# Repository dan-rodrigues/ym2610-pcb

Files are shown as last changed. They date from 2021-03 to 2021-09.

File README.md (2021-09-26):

# YM2610 PCB

This project allows the user to control a YM2610(B) FM synthesis / ADPCM / SSG sound chip. Software is included to play back YM2610(B) VGM files which includes any Neo Geo arcade game and various others. It can also play certain Sega Genesis tracks using an included converter script. There is also a MIDI input that can be paired with new software to control the synth.

The goal is to make the complete system both low-cost and flexible which increases the complexity of the FPGA design but allows the use of cheaper hardware (i.e. a $35USD FPGA board and a fairly straightforward PCB).

The FPGA board used is the [iCEBreaker Bitsy](https://1bitsquared.com/collections/fpga/products/icebreaker-bitsy) which is also [open source](https://github.com/icebreaker-fpga/icebreaker). It's the small purple board in the bottom left of the photo. A custom vendor USB device and a companion host Python script is used for control. The USB core used is [no2usb](https://github.com/no2fpga/no2usb).

## Assembled PCBs

### v1.1.0 (partial)

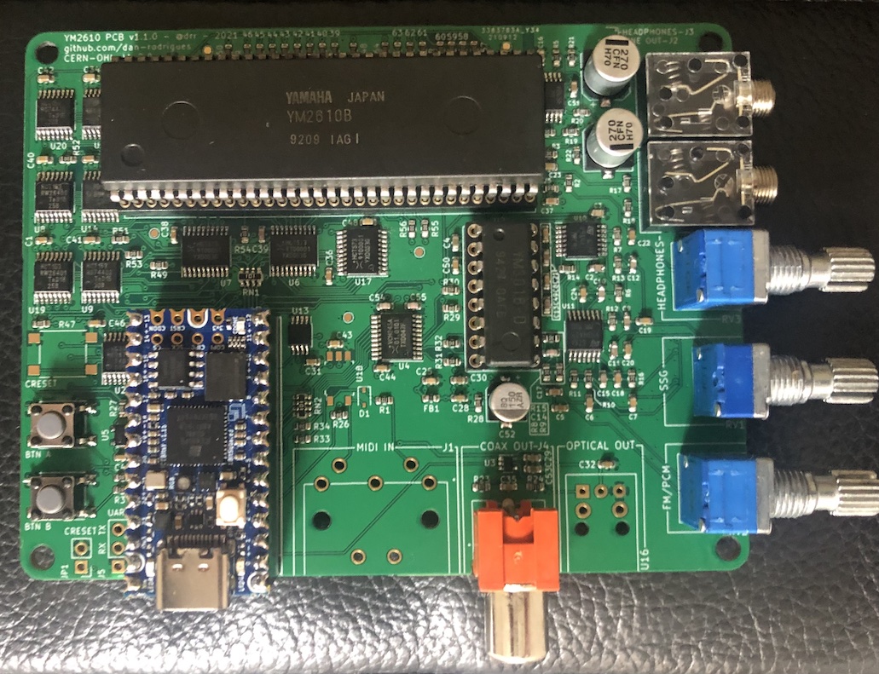
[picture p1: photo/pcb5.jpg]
v1.1.0 PCB partially assembled


### v1.0.1

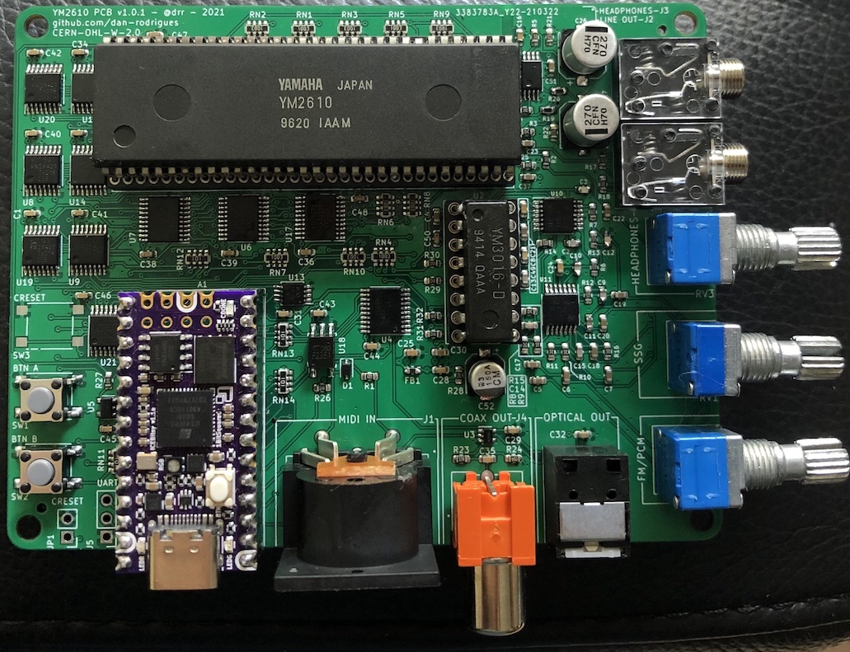
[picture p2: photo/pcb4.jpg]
v1.0.1 PCB assembled


## Video/Audio demos

* [Metal Slug 2 soundtrack](https://www.youtube.com/watch?v=nlexW8DgMvw) - Neo Geo VGM playback demo using S/PDIF audio output.
* [Thunder Force IV soundtrack](https://www.youtube.com/watch?v=O-OgxfgEnMU) - Sega Genesis playback demo using analog line-out output.

The Sega Genesis demos are made using an included converter script to compensate for incompatible hardware, different clock rates and differences in PCM playback.

## Features

### I/O

* S/PDIF compatible outputs. The digital sound sources from the OPNB (FM/PCM) can be heard using this output. The analog sound source (SSG) can only be heard with the 3.5mm analog outputs. Optical and coax outputs are included.
* 3.5mm line out.
* 3.5mm headphone out with attenutation pot.
* Separate attenuation pots for the combined FM/PCM and separate SSG sound sources. Their levels can be adjusted or muted independently.
* MIDI input (DIN-5). Default firmware includes library functions to read the MIDI messages into a minimal struct. There's also a simple FM demo.
* 2x user buttons. The default firmware uses them to cycle through the available sound sources.

The S/PDIF output is resampled to 48KHz and can be used to hear the original lossless output from the OPNB. It doesn't include the analog SSG output but most tracks don't use it.

The analog outputs include an active low pass filter (fC = approx 17KHz), independent attenutation pots for each sound source and can also be used to hear the analog SSG output.

### Debug

These aren't required but can be useful for debugging.

* UART header
* CRESET jumper
* CRESET button

## Operation

Included is also an SoC implementation for the FPGA (in the `rtl/` directory) and firmware that runs on this SoC (in the `fw/` directory). There's also a set of helper scripts to control the SoC over the USB port.

ADPCM samples are fetched from the FPGA board PSRAM. The host PCB itself doesn't include any extra memory, only some standard logic to mux the PCM buses to the limited number of FPGA IO available. The RAM is 64MBit which is smaller than the 128MBit address space of samples, but the player script relocates and remaps samples starting from address 0 if needed. This means tracks that use the 128MBit space will work assuming the total PCM size of the track is less than 64MBit, which it likely is.

Both the original YM3016 DAC and the FPGA have access to the digital outputs of the synth. This means both analog output (using the DAC) and digital output (using the coax/optical output) is available. S/PDIF encoding is done on the FPGA and made available from the digital outputs.

The synth has a pair of PCM buses that work in parallel and the board only includes a single RAM which must be shared. The slower of the two buses is automatically paused when the faster bus begins a read which handles the contention issue. Only 4 FPGA IOs are used to read the 26 PCM bus pins which is handled using standard logic on the board.

The iCEBreaker Bitsy USB port is used to upload music data and also for control. The USB stack used and firmware can be customised as needed i.e. to allow a PC MIDI interface to drive the OPNB, or to record the raw digital output to store on a file, or any other possible use.

There is only 128KByte of RAM available to the software which would limit the maximum size of track that can be played. The track commands are streamed over USB to get around this limit which means tracks can be arbitrarily large. A pair of 8KByte buffers are read/written to support playback of large tracks.

Synth commands are output using a pair of 8bit shift registers, running at the same 8MHz clock as the synth itself. This reduces the needed IO count without being a bottleneck.

## Usage

### Build and flash

This project uses submodules which must be cloned first.

```
git submodule update --init --recursive
```

Building and flashing FPGA bitstream (which implements the SoC):

```
make dfuprog
```

Building and flashing SoC firmware:

```
make -C fw dfuprog
```

### Playing VGM files

After flashing the firmware, the RGB LED should slowly flash indicating that it's ready to use. Either `vgz` or `vgm` files can be used.

```
./scripts/usb_ctrl.py track.vgm
```

More details about the scripts can be found in their [README](scripts/README.md) file.

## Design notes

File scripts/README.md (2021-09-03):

# Scripts

The [usb_ctrl.py](usb_ctrl.py) script is used to play VGM files over USB. Tracks played using usb_ctrl.py are automatically converted if needed before playback. YM2610(B) and YM2612 + PSG tracks are supported with the latter being converted before playback.

## Prerequisites

The [pyusb](https://github.com/pyusb/pyusb) library is required.

```
pip3 install -r requirements.txt
```

## Usage

These scripts can be used in one of two ways.

### USB driver

To upload a supported VGM file and start playback:

```
./usb_ctrl.py <vgm_file_to_play>
```

### VGM converter

A wrapper script can be used to do limited conversion of a YM2612 + SN76489 VGM to a YM2610B VGM. The output could also be played on a YM2608 since they have common FM / SSG sound sources. Note that the regular YM2610 (non-B variant) can play the result but only with 4 out of 6 FM channels.

* All OPN FM pitches are converted according to the input clock to an assumed 8MHz output clock so clock differences should not change the effective pitch.
* PSG square waves are replaced with equivalent SSG square waves with pitch adjustment, which then played using the integrated YM2149.
* The YM2612 DAC channel output is encoded as a set of ADPCM-B samples for playback on the YM2610.

Because the SN76489 and YM2149 don't have identical features, the conversion is only partial. There is currently no attempt to convert noise playback.

```
./vgm_convert.py <input_vgm> <output_vgm>
```

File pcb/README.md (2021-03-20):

# PCB

Included is the schematic and PCB layout of the board.

## Usage

Most ICs on the board are optional but a few are required in any case:

* 2x 74AHCT595: Shift registers to control the YM2610(B) and reset both the 2610 and the 3016.
* 1x 74LV1T34: Clock buffer, also shifts the 8MHz clock from 3.3v to 5v.

If ADPCM-A/B playback is needed, then these are required:

* 4x 74HCT153
* 1x 74LVC257
* 1x 74LVC2G08
* 1x 74LVC244

The analog section is optional assuming the SSG sound source isn't needed. To listen to the digital sound sources using S/PDIF output, there are optional optical and coax outputs. The coax output does not use a pulse transformer and one can be added if needed. 

## License

CERL-OHL-S-2.0. There is a copy of the text included in the licenses/ directory in the root of this repo. License text can also be found [here](https://ohwr.org/cern_ohl_s_v2.txt).

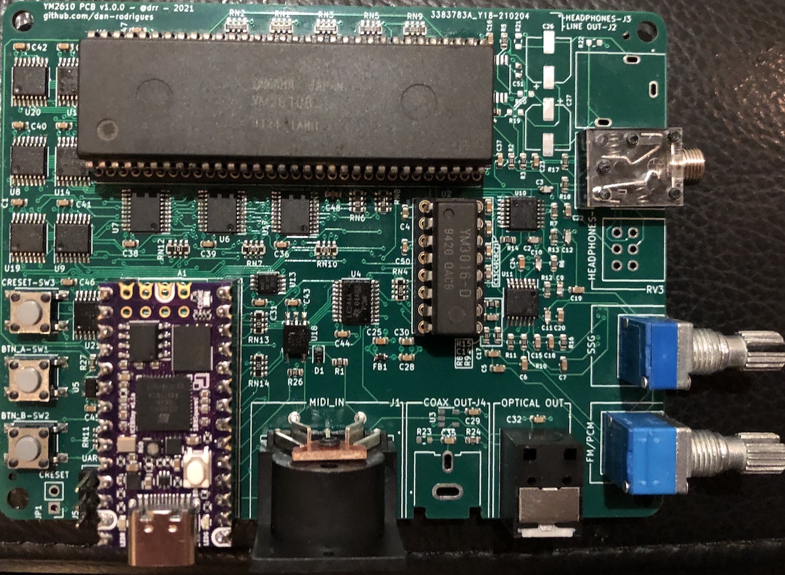
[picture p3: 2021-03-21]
photo/pcb2.jpg

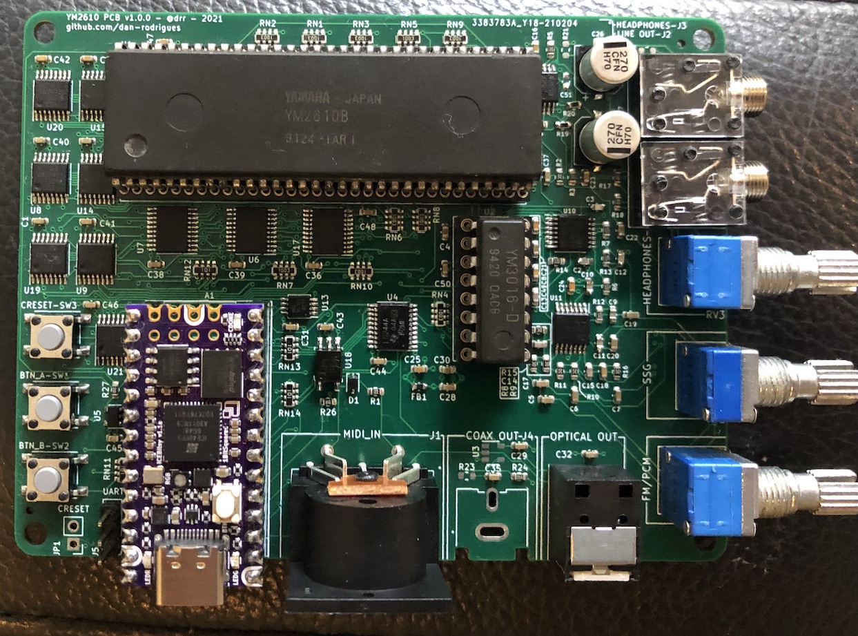
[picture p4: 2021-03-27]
photo/pcb3.jpg

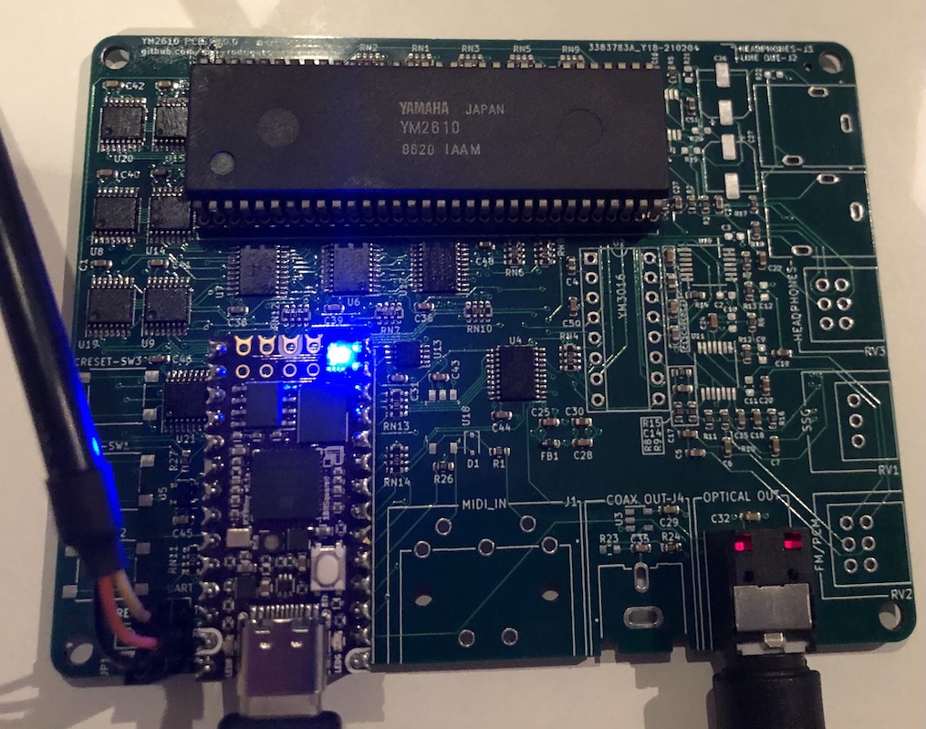
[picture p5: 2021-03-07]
photo/pcb1.jpg

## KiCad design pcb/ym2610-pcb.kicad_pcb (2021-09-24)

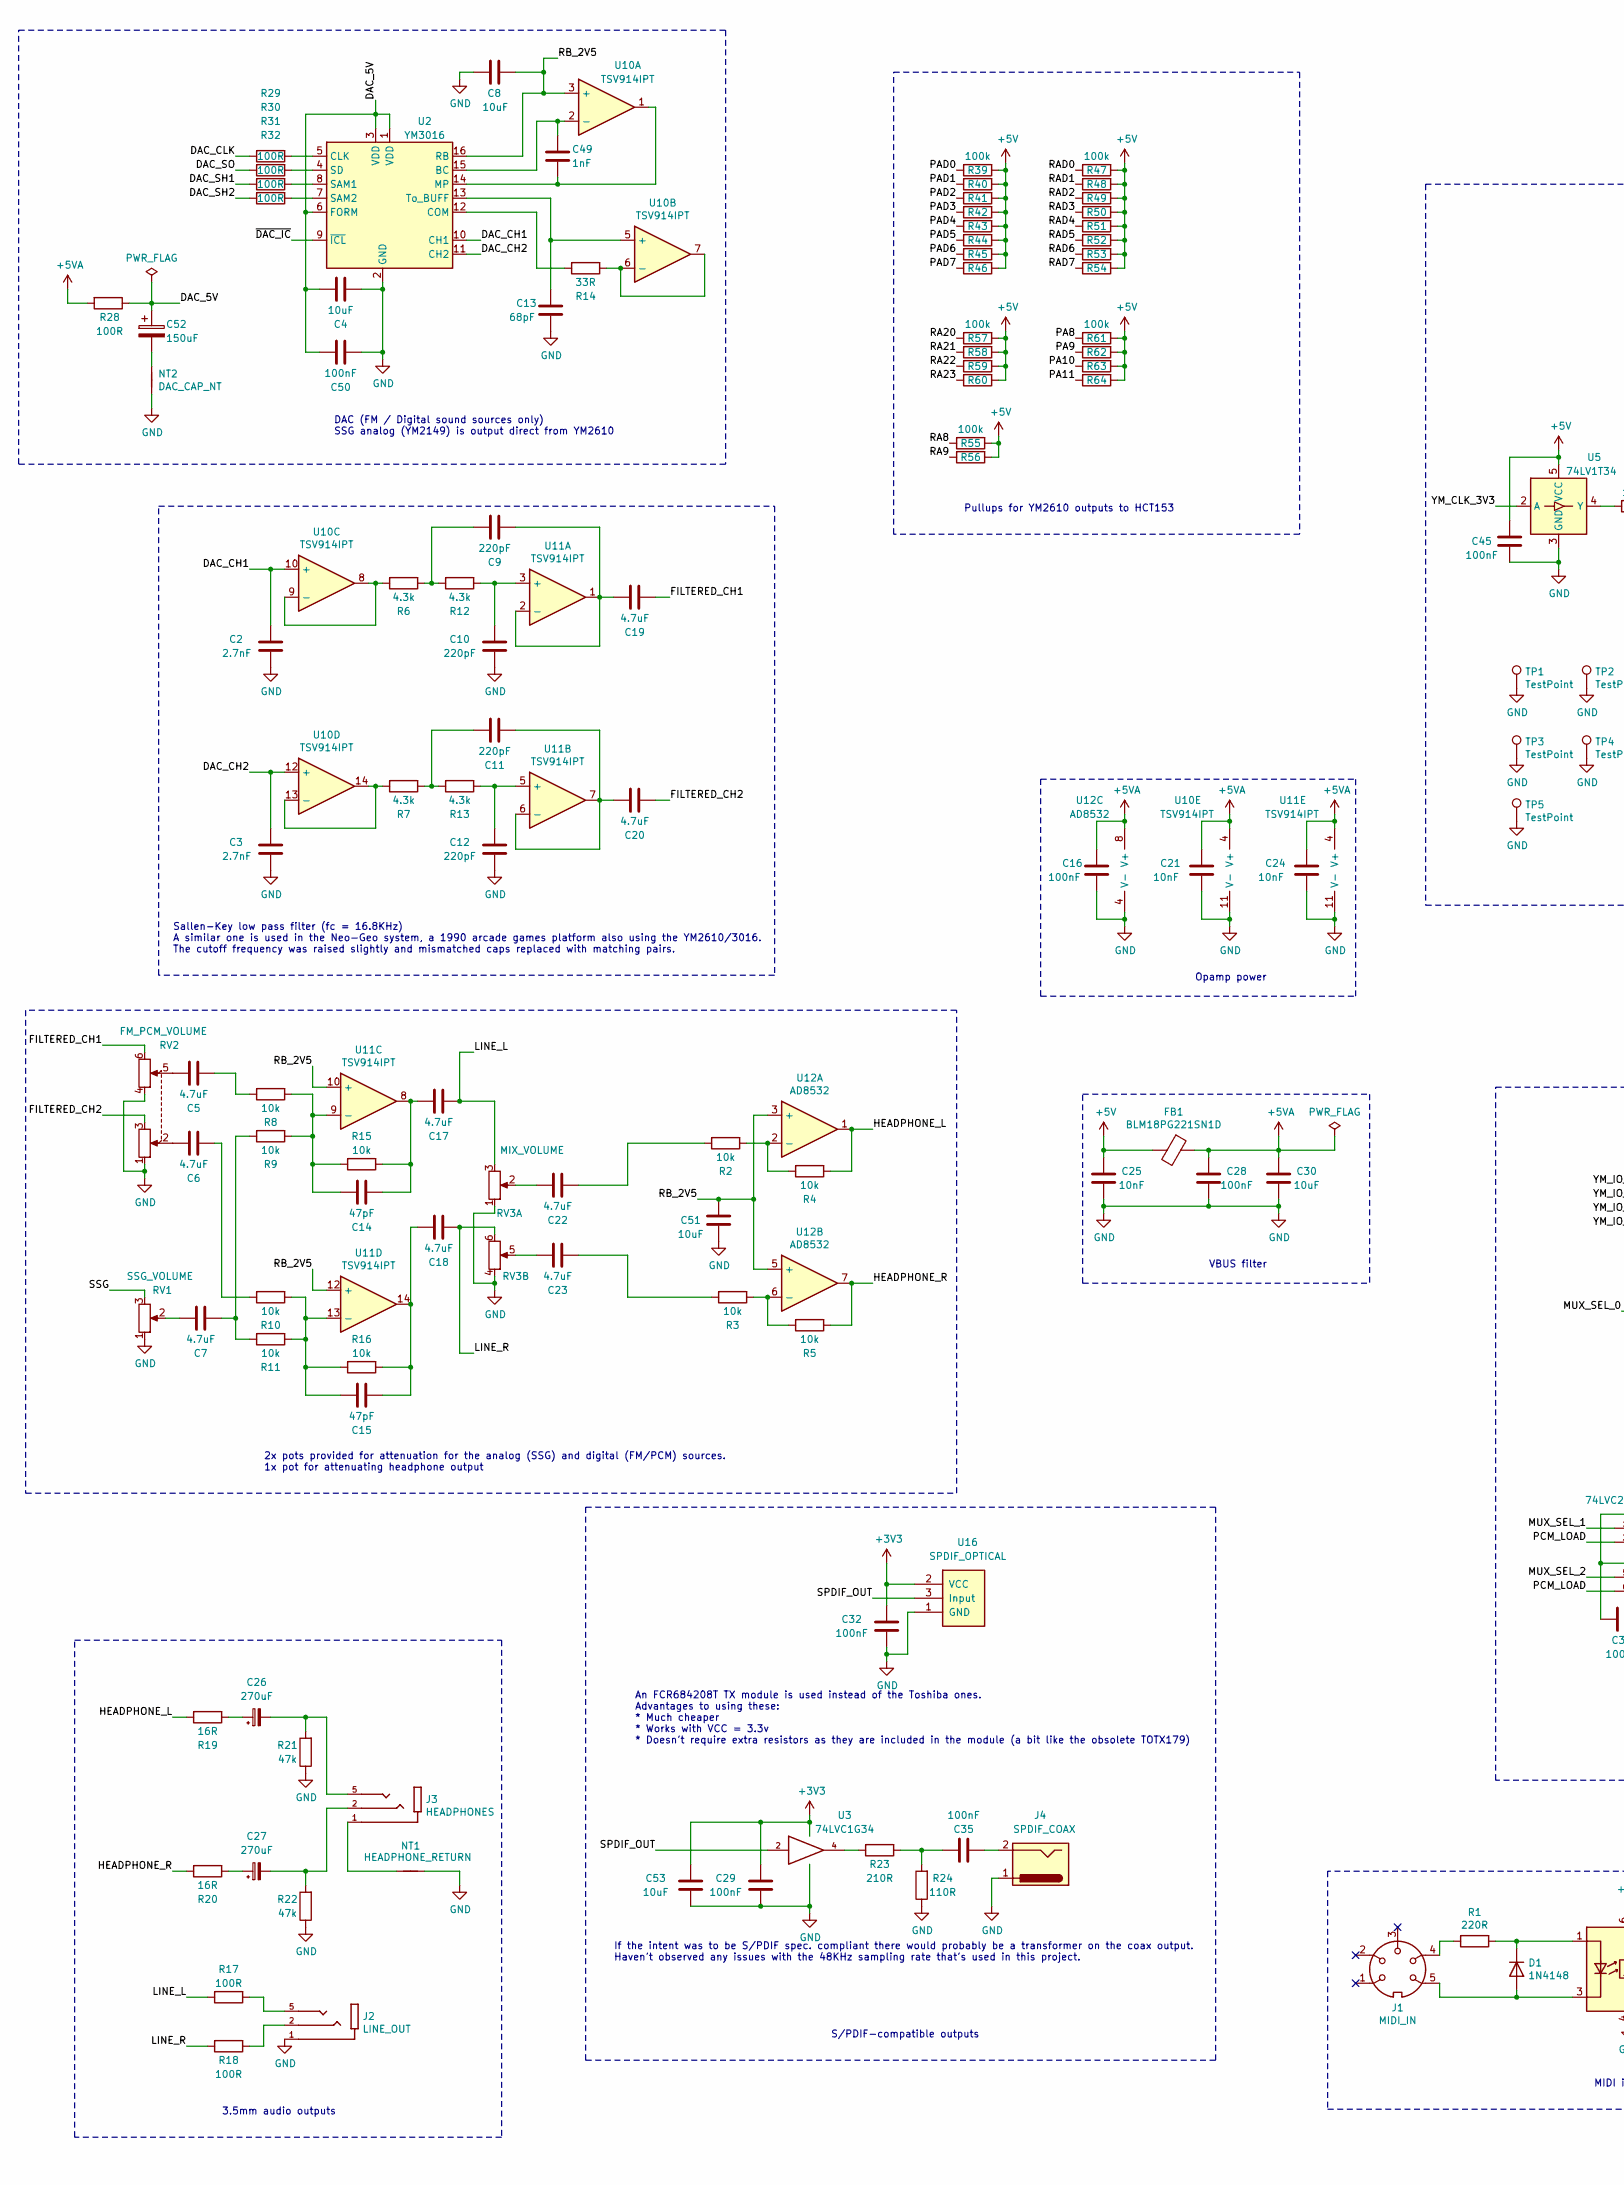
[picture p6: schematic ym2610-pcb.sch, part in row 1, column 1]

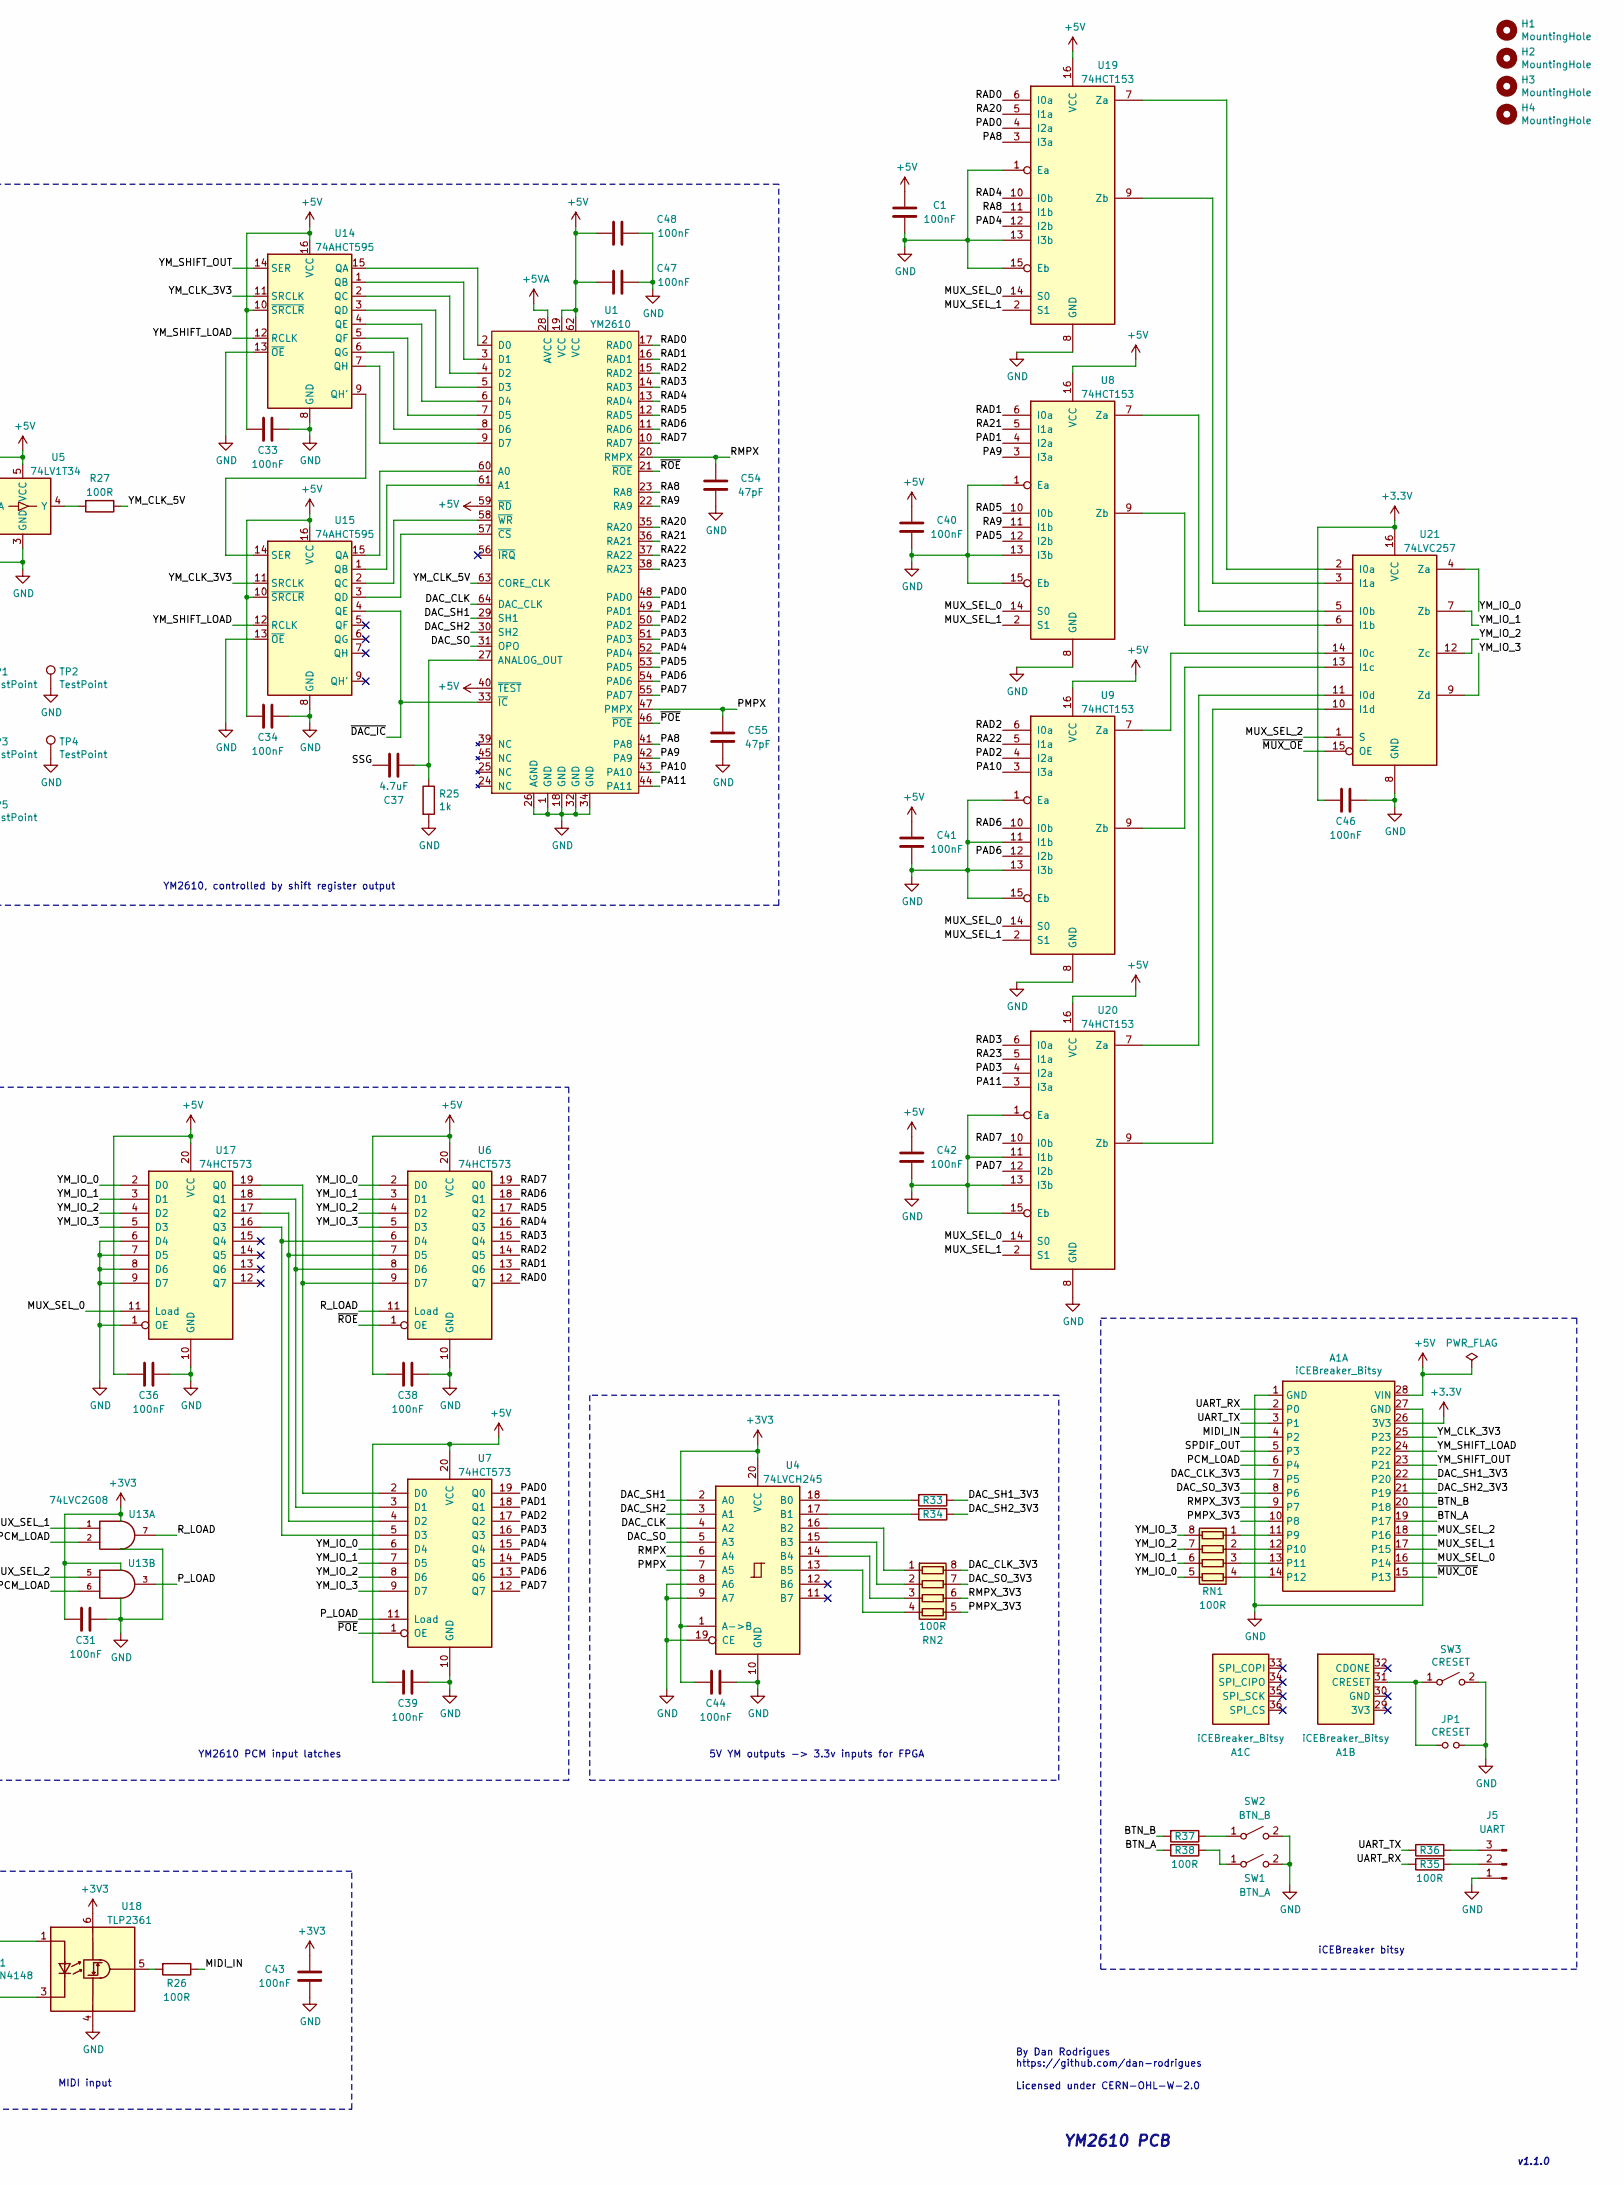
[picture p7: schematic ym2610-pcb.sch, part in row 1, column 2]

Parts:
A1: iCEBreaker_Bitsy; iCEBreaker_Bitsy_THT
C1, C29, C31, C32, C33, C34, C35, C36, C38, C39, C40, C41, C42, C44, C45, C46, C47, C48: 100nF; C_0603_1608Metric
C2, C3: 2.7nF; C_0603_1608Metric; Voltage 10v
C4, C8, C30, C51: 10uF; C_0603_1608Metric; Voltage 10v
C5, C6, C7, C17, C18, C19, C20, C22, C23, C37: 4.7uF; C_0603_1608Metric; Voltage 10v
C9, C10, C11, C12: 220pF; C_0603_1608Metric; Voltage 10v
C13: 68pF; C_0603_1608Metric; Voltage 10v
C14, C15: 47pF; C_0603_1608Metric; Voltage 10v; Tolerance 5%
C16, C28, C50: 100nF; C_0603_1608Metric; Voltage 10v
C21, C24, C25: 10nF; C_0603_1608Metric; Voltage 10v
C26, C27: 270uF; CP_Elec_6.3x7.7; Voltage 10v
C43: 100nF; C_0603_1608Metric; Voltage 3.3v
C49: 1nF; C_0603_1608Metric; Voltage 10v
C52: 150uF; CP_Elec_5x5.8; Voltage 10v
C53: 10uF; C_0603_1608Metric
C54, C55: 47pF; C_0603_1608Metric
D1: 1N4148; D_SOD-323
FB1: BLM18PG221SN1D; L_0603_1608Metric
H1, H2, H3, H4: MountingHole; MountingHole_3.2mm_M3_DIN965
J1: MIDI_IN; CUI_SDS-50J
J2: LINE_OUT; SWITCHCRAFT_35RAPC2BH3; PARTREV J
J3: HEADPHONES; SWITCHCRAFT_35RAPC2BH3; PARTREV J
J4: SPDIF_COAX; RCJ-04
J5: UART; PinHeader_1x03_P2.54mm_Vertical
JP1: CRESET; PinHeader_1x02_P2.54mm_Vertical
NT1: HEADPHONE_RETURN; NetTie-2_SMD_Pad0.5mm
NT2: DAC_CAP_NT; NetTie-2_SMD_Pad0.5mm
R1: 220R; R_0603_1608Metric
R2, R3, R4, R5: 10k; R_0603_1608Metric
R6, R7, R12, R13: 4.3k; R_0603_1608Metric; Tolerance 1%
R8, R9, R10, R11, R15, R16: 10k; R_0603_1608Metric; Tolerance 1%
R14: 33R; R_0603_1608Metric; Tolerance 1%
R17, R18, R26, R27, R28, R29, R30, R31, R32, R33, R34, R35, R36, R37, R38: 100R; R_0603_1608Metric
R19, R20: 16R; R_0603_1608Metric
R21, R22: 47k; R_0603_1608Metric
R23: 210R; R_0603_1608Metric
R24: 110R; R_0603_1608Metric
R25: 1k; R_0603_1608Metric; Tolerance 1%
R39, R40, R41, R42, R43, R44, R45, R46, R47, R48, R49, R50, R51, R52, R53, R54, R55, R56, R57, R58, R59, R60, R61, R62, R63, R64: 100k; R_0603_1608Metric
RN1, RN2: 100R; R_Array_Convex_4x0603
RV1: SSG_VOLUME; PTD901-2015K-A103
RV2: FM_PCM_VOLUME; PTD902-2020K-A103
RV3: MIX_VOLUME; PTD902-2020K-A103
SW1: BTN_A; SW_SPST_PTS645
SW2: BTN_B; SW_SPST_PTS645
SW3: CRESET; SW_SPST_PTS645
TP1, TP2, TP3, TP4, TP5: TestPoint; TestPoint_Pad_D1.0mm
U1: YM2610; DIP-64_W19.05mm_P1.78mm_Socket
U2: YM3016; DIP-16_W7.62mm_Socket
U3: 74LVC1G34; SOT-353_SC-70-5
U4: 74LVCH245; TSSOP-20_4.4x6.5mm_P0.65mm
U5: 74LV1T34; SOT-23-5
U6, U7, U17: 74HCT573; TSSOP-20_4.4x6.5mm_P0.65mm
U8, U9, U19, U20: 74HCT153; TSSOP-16_4.4x5mm_P0.65mm
U10, U11: TSV914IPT; TSSOP-14_4.4x5mm_P0.65mm
U12: AD8532; TSSOP-8_4.4x3mm_P0.65mm
U13: 74LVC2G08; TSSOP-8_3x3mm_P0.65mm
U14, U15: 74AHCT595; TSSOP-16_4.4x5mm_P0.65mm
U16: SPDIF_OPTICAL; FCR684208T
U18: TLP2361; SOIC-6-5_W4.55mm
U21: 74LVC257; TSSOP-16_4.4x5mm_P0.65mm

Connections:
+5V: A1.28 (VIN), C1.2, C25.1, C33.2, C34.2, C36.1, C38.2, C39.2, C40.2, C41.2, C42.2, C45.2, C47.2, C48.2, FB1.2, R39.1, R40.1, R41.1, R42.1, R43.1, R44.1, R45.1, R46.1, R47.1, R48.1, R49.1, R50.1, R51.1, R52.1, R53.1, R54.1, R55.1, R56.1, R57.1, R58.1, R59.1, R60.1, R61.1, R62.1, R63.1, R64.1, U1.19 (VCC), U1.40 (~TEST), U1.59 (~RD), U1.62 (VCC), U5.5 (VCC), U6.20 (VCC), U7.20 (VCC), U8.16 (VCC), U9.16 (VCC), U14.10 (~SRCLR), U14.16 (VCC), U15.10 (~SRCLR), U15.16 (VCC), U17.20 (VCC), U19.16 (VCC), U20.16 (VCC)
+5VA: C16.1, C21.1, C24.1, C28.1, C30.1, FB1.1, R28.2, U1.28 (AVCC), U10.4 (V+), U11.4 (V+), U12.8 (V+)
/BTN_A: A1.19 (P17), R38.2
/BTN_B: A1.20 (P18), R37.2
/DAC_5V: C4.2, C50.2, C52.1, R28.1, U2.1 (VDD), U2.3 (VDD), U2.6 (FORM)
/DAC_CH1: C2.1, U2.10 (CH1), U10.10 (+)
/DAC_CH2: C3.1, U2.11 (CH2), U10.12 (+)
/DAC_CLK: R29.2, U1.64 (DAC_CLK), U4.4 (A2)
/DAC_CLK_3V3: A1.7 (P5), RN2.8 (R1.2)
/DAC_SH1: R31.2, U1.29 (SH1), U4.2 (A0)
/DAC_SH1_3V3: A1.22 (P20), R33.1
/DAC_SH2: R32.2, U1.30 (SH2), U4.3 (A1)
/DAC_SH2_3V3: A1.21 (P19), R34.1
/DAC_SO: R30.2, U1.31 (OPO), U4.5 (A3)
/DAC_SO_3V3: A1.8 (P6), RN2.7 (R2.2)
/FILTERED_CH1: C19.1, RV2.6
/FILTERED_CH2: C20.1, RV2.3
/HEADPHONE_L: R4.1, R19.2, U12.1
/HEADPHONE_R: R5.1, R20.2, U12.7
/LINE_L: C17.1, R17.2, RV3.3
/LINE_R: C18.1, R18.2, RV3.6
/MIDI_IN: A1.4 (P2), R26.1
/MUX_SEL_0: A1.16 (P14), U8.14 (S0), U9.14 (S0), U17.11 (Load), U19.14 (S0), U20.14 (S0)
/MUX_SEL_1: A1.17 (P15), U8.2 (S1), U9.2 (S1), U13.1, U19.2 (S1), U20.2 (S1)
/MUX_SEL_2: A1.18 (P16), U13.5, U21.1 (S)
/PA8: R61.2, U1.41 (PA8), U19.3 (I3a)
/PA9: R62.2, U1.42 (PA9), U8.3 (I3a)
/PA10: R63.2, U1.43 (PA10), U9.3 (I3a)
/PA11: R64.2, U1.44 (PA11), U20.3 (I3a)
/PAD0: R39.2, U1.48 (PAD0), U7.19 (Q0), U19.4 (I2a)
/PAD1: R40.2, U1.49 (PAD1), U7.18 (Q1), U8.4 (I2a)
/PAD2: R41.2, U1.50 (PAD2), U7.17 (Q2), U9.4 (I2a)
/PAD3: R42.2, U1.51 (PAD3), U7.16 (Q3), U20.4 (I2a)
/PAD4: R43.2, U1.52 (PAD4), U7.15 (Q4), U19.12 (I2b)
/PAD5: R44.2, U1.53 (PAD5), U7.14 (Q5), U8.12 (I2b)
/PAD6: R45.2, U1.54 (PAD6), U7.13 (Q6), U9.12 (I2b)
/PAD7: R46.2, U1.55 (PAD7), U7.12 (Q7), U20.12 (I2b)
/PCM_LOAD: A1.6 (P4), U13.2, U13.6
/PMPX: C55.2, U1.47 (PMPX), U4.7 (A5)
/PMPX_3V3: A1.10 (P8), RN2.5 (R4.2)
/P_LOAD: U7.11 (Load), U13.3
/RA8: R55.2, U1.23 (RA8), U19.11 (I1b)
/RA9: R56.2, U1.22 (RA9), U8.11 (I1b)
/RA20: R57.2, U1.35 (RA20), U19.5 (I1a)
/RA21: R58.2, U1.36 (RA21), U8.5 (I1a)
/RA22: R59.2, U1.37 (RA22), U9.5 (I1a)
/RA23: R60.2, U1.38 (RA23), U20.5 (I1a)
/RAD0: R47.2, U1.17 (RAD0), U6.12 (Q7), U19.6 (I0a)
/RAD1: R48.2, U1.16 (RAD1), U6.13 (Q6), U8.6 (I0a)
/RAD2: R49.2, U1.15 (RAD2), U6.14 (Q5), U9.6 (I0a)
/RAD3: R50.2, U1.14 (RAD3), U6.15 (Q4), U20.6 (I0a)
/RAD4: R51.2, U1.13 (RAD4), U6.16 (Q3), U19.10 (I0b)
/RAD5: R52.2, U1.12 (RAD5), U6.17 (Q2), U8.10 (I0b)
/RAD6: R53.2, U1.11 (RAD6), U6.18 (Q1), U9.10 (I0b)
/RAD7: R54.2, U1.10 (RAD7), U6.19 (Q0), U20.10 (I0b)
/RB_2V5: C8.1, C51.2, U2.16 (RB), U10.3 (+), U11.10 (+), U11.12 (+), U12.3 (+), U12.5 (+)
/RMPX: C54.2, U1.20 (RMPX), U4.6 (A4)
/RMPX_3V3: A1.9 (P7), RN2.6 (R3.2)
/R_LOAD: U6.11 (Load), U13.7
/SPDIF_OUT: A1.5 (P3), U3.2, U16.3 (Input)
/SSG: C37.2, RV1.3
/UART_RX: A1.2 (P0), R35.1
/UART_TX: A1.3 (P1), R36.1
/YM_CLK_3V3: A1.25 (P23), U5.2 (A), U14.11 (SRCLK), U15.11 (SRCLK)
/YM_CLK_5V: R27.1, U1.63 (CORE_CLK)
/YM_IO_0: RN1.5 (R4.2), U6.2 (D0), U7.6 (D4), U17.2 (D0), U21.4 (Za)
/YM_IO_1: RN1.6 (R3.2), U6.3 (D1), U7.7 (D5), U17.3 (D1), U21.7 (Zb)
/YM_IO_2: RN1.7 (R2.2), U6.4 (D2), U7.8 (D6), U17.4 (D2), U21.12 (Zc)
/YM_IO_3: RN1.8 (R1.2), U6.5 (D3), U7.9 (D7), U17.5 (D3), U21.9 (Zd)
/YM_SHIFT_LOAD: A1.24 (P22), U14.12 (RCLK), U15.12 (RCLK)
/YM_SHIFT_OUT: A1.23 (P21), U14.14 (SER)
/~DAC_IC: U1.33 (~IC), U2.9 (~ICL), U15.4 (QE)
/~MUX_OE: A1.15 (P13), U21.15 (OE)
/~POE: U1.46 (~POE), U7.1 (OE)
/~ROE: U1.21 (~ROE), U6.1 (OE)
GND: A1.1 (GND), A1.27 (GND), C1.1, C2.2, C3.2, C4.1, C8.2, C10.1, C12.1, C13.2, C16.2, C21.2, C24.2, C25.2, C28.2, C29.1, C30.2, C31.2, C32.1, C33.1, C34.1, C36.2, C38.1, C39.1, C40.1, C41.1, C42.1, C43.1, C44.1, C45.1, C46.1, C47.1, C48.1, C50.1, C51.1, C53.1, C54.1, C55.1, J2.1, J4.1, J5.1, JP1.2, NT1.2, NT2.2, R21.1, R22.1, R24.1, R25.2, RV1.1, RV2.1, RV2.4, RV3.1, RV3.4, SW1.2 (B), SW2.2 (B), SW3.2 (B), TP1.1, TP2.1, TP3.1, TP4.1, TP5.1, U1.1 (GND), U1.18 (GND), U1.26 (AGND), U1.32 (GND), U1.34 (GND), U2.2 (GND), U3.3 (GND), U4.8 (A6), U4.9 (A7), U4.10 (GND), U4.19 (CE), U5.3 (GND), U6.10 (GND), U7.10 (GND), U8.1 (Ea), U8.8 (GND), U8.13 (I3b), U8.15 (Eb), U9.1 (Ea), U9.8 (GND), U9.11 (I1b), U9.13 (I3b), U9.15 (Eb), U10.11 (V-), U11.11 (V-), U12.4 (V-), U13.4 (GND), U14.8 (GND), U14.13 (~OE), U15.8 (GND), U15.13 (~OE), U16.1 (GND), U17.1 (OE), U17.6 (D4), U17.7 (D5), U17.8 (D6), U17.9 (D7), U17.10 (GND), U18.4 (GND), U19.1 (Ea), U19.8 (GND), U19.13 (I3b), U19.15 (Eb), U20.1 (Ea), U20.8 (GND), U20.11 (I1b), U20.13 (I3b), U20.15 (Eb), U21.8 (GND)
unnamed: A1.11 (P9), RN1.1 (R1.1)
unnamed: A1.12 (P10), RN1.2 (R2.1)
unnamed: A1.13 (P11), RN1.3 (R3.1)
unnamed: A1.14 (P12), RN1.4 (R4.1)
unnamed: A1.31 (CRESET), JP1.1, SW3.1 (A)
unnamed: C5.1, R8.2
unnamed: C5.2, RV2.5
unnamed: C6.1, R10.2
unnamed: C6.2, RV2.2
unnamed: C7.1, R9.2, R11.2
unnamed: C7.2, RV1.2
unnamed: C9.2, R6.1, R12.2
unnamed: C10.2, R12.1, U11.3 (+)
unnamed: C11.1, C20.2, U11.6 (-), U11.7
unnamed: C11.2, R7.1, R13.2
unnamed: C12.2, R13.1, U11.5 (+)
unnamed: C13.1, U2.13 (To_BUFF), U10.5 (+)
unnamed: C14.1, C17.2, R15.1, U11.8
unnamed: C14.2, R8.1, R9.1, R15.2, U11.9 (-)
unnamed: C15.1, C18.2, R16.1, U11.14
unnamed: C15.2, R10.1, R11.1, R16.2, U11.13 (-)
unnamed: C9.1, C19.2, U11.1, U11.2 (-)
unnamed: C22.1, R2.2
unnamed: C22.2, RV3.2
unnamed: C23.1, R3.2
unnamed: C23.2, RV3.5
unnamed: C26.1, R19.1
unnamed: C26.2, J3.5, R21.2
unnamed: C27.1, R20.1
unnamed: C27.2, J3.2, R22.2
unnamed: C35.1, J4.2
unnamed: C35.2, R23.1, R24.2
unnamed: C37.1, R25.1, U1.27 (ANALOG_OUT)
unnamed: C49.1, U2.14 (MP), U10.1
unnamed: C49.2, U2.15 (BC), U10.2 (-)
unnamed: C52.2, NT2.1
unnamed: D1.1 (K), R1.1, U18.1 (A)
unnamed: D1.2 (A), J1.5, U18.3 (K)
unnamed: J1.4, R1.2
unnamed: J2.2, R18.1
unnamed: J2.5, R17.1
unnamed: J3.1, NT1.1
unnamed: J5.2, R35.2
unnamed: J5.3, R36.2
unnamed: R2.1, R4.2, U12.2 (-)
unnamed: R3.1, R5.2, U12.6 (-)
unnamed: R6.2, U10.8, U10.9 (-)
unnamed: R7.2, U10.13 (-), U10.14
unnamed: R14.1, U10.6 (-), U10.7
unnamed: R14.2, U2.12 (COM)
unnamed: R23.2, U3.4
unnamed: R26.2, U18.5 (VO)
unnamed: R27.2, U5.4 (Y)
unnamed: R29.1, U2.5 (CLK)
unnamed: R30.1, U2.4 (SD)
unnamed: R31.1, U2.8 (SAM1)
unnamed: R32.1, U2.7 (SAM2)
unnamed: R33.2, U4.18 (B0)
unnamed: R34.2, U4.17 (B1)
unnamed: R37.1, SW2.1 (A)
unnamed: R38.1, SW1.1 (A)
unnamed: RN2.1 (R1.1), U4.16 (B2)
unnamed: RN2.2 (R2.1), U4.15 (B3)
unnamed: RN2.3 (R3.1), U4.14 (B4)
unnamed: RN2.4 (R4.1), U4.13 (B5)
unnamed: U1.2 (D0), U14.15 (QA)
unnamed: U1.3 (D1), U14.1 (QB)
unnamed: U1.4 (D2), U14.2 (QC)
unnamed: U1.5 (D3), U14.3 (QD)
unnamed: U1.6 (D4), U14.4 (QE)
unnamed: U1.7 (D5), U14.5 (QF)
unnamed: U1.8 (D6), U14.6 (QG)
unnamed: U1.9 (D7), U14.7 (QH)
unnamed: U1.57 (~CS), U15.3 (QD)
unnamed: U1.58 (~WR), U15.2 (QC)
unnamed: U1.60 (A0), U15.15 (QA)
unnamed: U1.61 (A1), U15.1 (QB)
unnamed: U14.9 (QH'), U15.14 (SER)
unnamed: U6.6 (D4), U7.5 (D3), U17.16 (Q3)
unnamed: U6.7 (D5), U7.4 (D2), U17.17 (Q2)
unnamed: U6.8 (D6), U7.3 (D1), U17.18 (Q1)
unnamed: U6.9 (D7), U7.2 (D0), U17.19 (Q0)
unnamed: U19.7 (Za), U21.2 (I0a)
unnamed: U19.9 (Zb), U21.3 (I1a)
unnamed: U20.7 (Za), U21.11 (I0d)
unnamed: U20.9 (Zb), U21.10 (I1d)
unnamed: U8.7 (Za), U21.5 (I0b)
unnamed: U8.9 (Zb), U21.6 (I1b)
unnamed: U9.9 (Zb), U21.13 (I1c)
unnamed: U9.7 (Za), U21.14 (I0c)

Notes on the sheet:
Sallen-Key low pass filter (fc = 16.8KHz) A similar one is used in the Neo-Geo system, a 1990 arcade games platform also using the YM2610/3016. The cutoff frequency was raised slightly and mismatched caps replaced with matching pairs.
VBUS filter
2x pots provided for attenuation for the analog (SSG) and digital (FM/PCM) sources. 1x pot for attenuating headphone output
If the intent was to be S/PDIF spec. compliant there would probably be a transformer on the coax output. Haven’t observed any issues with the 48KHz sampling rate that’s used in this project.
An FCR684208T TX module is used instead of the Toshiba ones. Advantages to using these: * Much cheaper * Works with VCC = 3.3v * Doesn’t require extra resistors as they are included in the module (a bit like the obsolete TOTX179)
3.5mm audio outputs
S/PDIF-compatible outputs
MIDI input
Pullups for YM2610 outputs to HCT153
DAC (FM / Digital sound sources only) SSG analog (YM2149) is output direct from YM2610
YM2610 PCM input latches
YM2610, controlled by shift register output
5V YM outputs -> 3.3v inputs for FPGA
iCEBreaker bitsy
Opamp power
YM2610 PCB
v1.1.0
By Dan Rodrigues https://github.com/dan-rodrigues Licensed under CERN-OHL-W-2.0

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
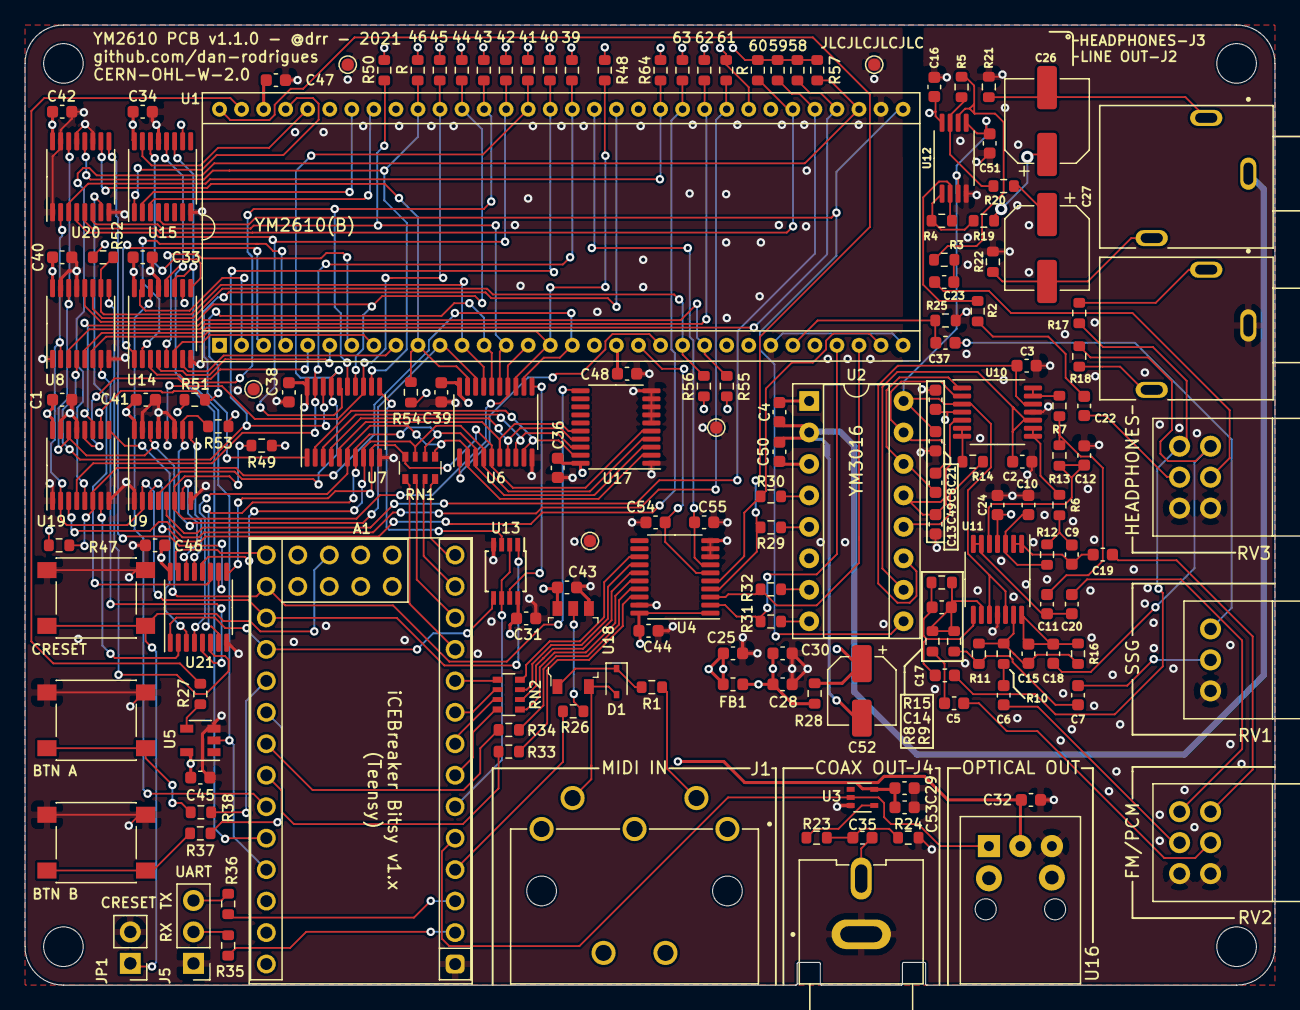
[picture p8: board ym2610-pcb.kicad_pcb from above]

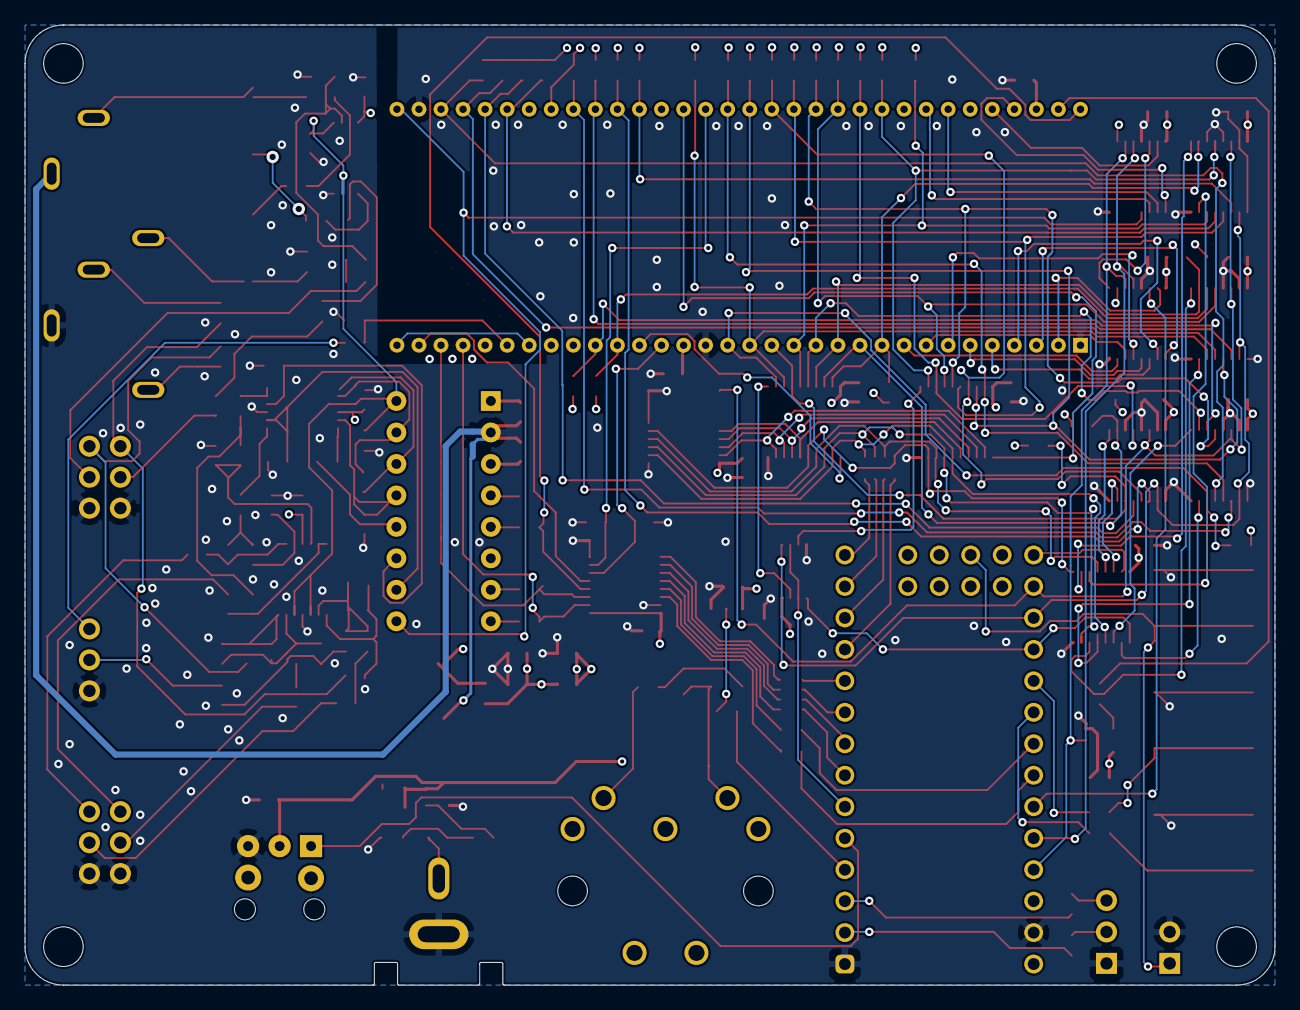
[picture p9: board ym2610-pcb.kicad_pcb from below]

Board: 4 copper layers, 100.9 x 77.5 mm, 168 parts (2 on the bottom side), 167 nets.

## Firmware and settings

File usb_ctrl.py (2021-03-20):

#!/usr/bin/env python3

# usb_ctrl.py
#
# Copyright (C) 2021 Dan Rodrigues <danrr.gh.oss@gmail.com>
#
# SPDX-License-Identifier: MIT

import sys

import usb.core
import usb.util

import binascii
import struct
import sys
from pathlib import Path
from enum import Enum

import threading
import time

class PCMType(Enum):
	A = 0
	B = 1

class PCMBlock:
	def __init__(self):
		self.offset = 0
		self.data = []
		self.type = PCMType.A

class ProcessedVGM:
	def __init__(self):
		self.data = []
		self.pcm_blocks = []

	def __repr__(self):
		return "ProcessedVGM:\nCommand data length: {:X}\nPCM blocks: {:X}\n" \
			.format(len(self.data), len(self.pcm_blocks))

def get_data_ep(dev):
	cfg = dev.get_active_configuration()
	intf = cfg[(1,0)]

	# The single bulk OUT endpoint is the one that will be used for PCM / VGM data writing
	ep = usb.util.find_descriptor(
		intf,
		custom_match = \
		lambda e: \
			usb.util.endpoint_direction(e.bEndpointAddress) == usb.util.ENDPOINT_OUT and \
			usb.util.endpoint_type(e.bmAttributes) == usb.util.ENDPOINT_TYPE_BULK \
			)

	if ep is None:
		print("Data endpoint not found")
		sys.exit(1)

	return ep

def get_status_ep(dev):
	cfg = dev.get_active_configuration()
	intf = cfg[(1,0)]

	# The status EP that is used by this script to monitor state, respond requests etc.
	ep = usb.util.find_descriptor(
		intf,
		custom_match = \
		lambda e: \
			usb.util.endpoint_direction(e.bEndpointAddress) == usb.util.ENDPOINT_IN and \
			usb.util.endpoint_type(e.bmAttributes) == usb.util.ENDPOINT_TYPE_INTR \
			)

	if ep is None:
		print("Status endpoint not found")
		sys.exit(1)

	return ep


def read_vgm(path):
	with open(path, "rb") as vgm_file:
		vgm = vgm_file.read()

	if len(vgm) == 0:
		print("VGM file is empty: ", path)
		sys.exit(1)

	return vgm

###

class WriteMode(Enum):
	PCM_A = 0x00
	PCM_B = 0x01
	VGM = 0x02

def set_write_mode(dev, write_mode, length, offset):
	CTRL_SET_WRITE_MODE = 0x00
	REQUEST_TYPE = 0x41

	offset_bytes = offset.to_bytes(4, 'little')
	length_bytes = length.to_bytes(4, 'little')
	data_bytes = offset_bytes + length_bytes 

	dev.ctrl_transfer(REQUEST_TYPE, CTRL_SET_WRITE_MODE, write_mode.value, 0, data_bytes)

def send_vgm(dev, ep, vgm, offset=0, restart_playback=True):
	CTRL_READ_STATUS = 0x80
	CTRL_START_PLAYBACK = 0x01
	REQUEST_TYPE = 0x41

	# Prepare for writing..
	set_write_mode(dev, WriteMode.VGM, len(vgm), offset)

	# ..write..
	ep.write(vgm, 20000)

	if restart_playback:
		# ..start playback after writing
		dev.ctrl_transfer(REQUEST_TYPE, CTRL_START_PLAYBACK, 0, 0)

def send_pcm(dev, ep, block):
	set_write_mode(dev, WriteMode.PCM_A if block.type == PCMType.A else WriteMode.PCM_B, len(block.data), block.offset)
	ep.write(block.data, 20000)

def send_pcm_blocks(dev, ep, pcm_blocks):
	for block in pcm_blocks:
		send_pcm(dev, ep, block)

###

def poll_status(stopping_event, status_ep, data_ep, processed_vgm):
	print("Polling for status...")

	vgm_data = processed_vgm.data

	while not stopping_event.is_set():
		try:
			BUFFERING_REQUEST_HEADER = 0x01
			STATUS_TOTAL_LENGTH = 16

			status_data = status_ep.read(STATUS_TOTAL_LENGTH, 250)
			print("Received status data: ", binascii.hexlify(status_data))

			header = int.from_bytes(status_data[0 : 4], byteorder='little')
			if header != BUFFERING_REQUEST_HEADER:
				print("Ignoring request with header: ", header)
				continue

			buffer_target_offset = int.from_bytes(status_data[4 : 8], byteorder='little')
			vgm_start_offset = int.from_bytes(status_data[8 : 12], byteorder='little')
			vgm_chunk_length = int.from_bytes(status_data[12 : 16], byteorder='little')

			print("Sending VGM chunk to buffer @ {:X}, VGM offset: {:X}, Length: {:X}"\
				  .format(buffer_target_offset, vgm_start_offset, vgm_chunk_length))

			vgm_chunk = vgm_data[vgm_start_offset : vgm_start_offset + vgm_chunk_length]

			send_vgm(dev, data_ep, vgm_chunk, buffer_target_offset, restart_playback=False)

		except usb.core.USBError as e:
			# Swallowing exceptions like this is dirty but there are several coming in as "timeouts"
			# FIXME: filter out the exceptions of interest and raise the non-timeout related ones
			continue

def start_polling_status(dev, status_ep, data_ep, processed_vgm):
	stopping_event = threading.Event()
	thread = threading.Thread(target=poll_status, args=(stopping_event, status_ep, data_ep, processed_vgm))
	thread.daemon = True
	thread.start()
	return (thread, stopping_event)

###

def preprocess_vgm(vgm):
	relative_offset_index = 0x34
	relative_offset = int.from_bytes(vgm[relative_offset_index : relative_offset_index + 4], byteorder='little')
	start_index = relative_offset_index + relative_offset if relative_offset else 0x40
	print("VGM start index: {:X}".format(start_index))

	loop_offset_index = 0x1c
	loop_offset = int.from_bytes(vgm[loop_offset_index : loop_offset_index + 4], byteorder='little')
	loop_index = loop_offset + loop_offset_index if loop_offset else 0
	print("VGM loop index: {:X}".format(loop_index))

	index = start_index

	processed_vgm = ProcessedVGM()
	vgm_bytes = bytearray(vgm)

	flag_writes_removed = 0

	###

	def remove_block(length):
		nonlocal vgm_bytes, index, loop_index

		end = index + length
		del vgm_bytes[index : end]

		# Loop index may need adjusting if removal of PCM block displaced it
		if index < loop_index:
			block_size = end - index
			loop_index -= block_size

		index -= 1

	def check_reg_write():
		nonlocal vgm_bytes, index, flag_writes_removed

		REG_FLAGS = 0x1c

		cmd = vgm_bytes[index + 0]
		reg = vgm_bytes[index + 1]
		address = cmd & 0x01

		removed_bytes = 0

		# Flag writes have no effect on playback and should be removed
		if address == 0 and reg == REG_FLAGS:
			removed_bytes = 3
			remove_block(removed_bytes)
			flag_writes_removed += 1

		# YM2612 writes need to be remapped as YM2610 writes
		if cmd in [0x52, 0x53]:
			vgm_bytes[index] += 6

		index += 2 - removed_bytes

	###

	while index < len(vgm_bytes):
		cmd = vgm_bytes[index]

		if cmd in [0x58, 0x59, 0x52, 0x53]:
			check_reg_write()
		elif (cmd & 0xf0) == 0x70:
			pass
		elif cmd == 0x61:
			index += 2
		elif cmd == 0x62 or cmd == 0x63:
			pass
		elif cmd == 0x66:
			break
		elif cmd == 0x4f:
			# PSG stereo writes which sometimes appear but aren't used
			remove_block(2)
		elif cmd == 0x50:
			# PSG write, needs mapping
			remove_block(2)
		elif (cmd & 0xf0) == 0x80:
			# YM2612 PCM writes not supported
			remove_block(1)
		elif cmd == 0x67:
			block_type = vgm_bytes[index + 2]
			block_size = int.from_bytes(vgm_bytes[index + 3 : index + 7], byteorder='little')
			block_size -= 8
			if block_size <= 0:
				print("Expected PCM block size to be > 0")

			print('PCM block size: {:X}'.format(block_size))

			if block_type != 0x82 and block_type != 0x83:
				print("Unexpected block type: {:X}".format(block_type))
				sys.exit(1)

			total_size = int.from_bytes(vgm_bytes[index + 7 : index + 11], byteorder='little')
			if total_size == 0:
				print('Expected total_size to be > 0')
				sys.exit(1)

			offset = int.from_bytes(vgm_bytes[index + 11 : index + 15], byteorder='little')

			is_adpcm_a = block_type == 0x82

			print('Found block: type ', 'A' if is_adpcm_a else 'B')
			print('Size: {:X}, offset: {:X}, total: {:X}'.format(block_size, offset, total_size))

			# Some PCM blocks are 0 size for whatever reason, just ignore them
			if block_size > 0:
				pcm_block = PCMBlock()
				pcm_block.offset = offset
				pcm_block.data = vgm_bytes[index + 15 : index + 15 + block_size]
				pcm_block.type = PCMType.A if is_adpcm_a else PCMType.B
				processed_vgm.pcm_blocks.append(pcm_block)

			# Remove PCM block portion from VGM as it's preloaded in separate write step(s)
			remove_block(block_size + 15)

		index += 1


	# Reassign possibly adjusted loop offset due to PCM block removal above
	adjusted_loop_offset = loop_index - loop_offset_index
	loop_offset_bytes = adjusted_loop_offset.to_bytes(4, 'little')
	vgm_bytes[loop_offset_index : loop_offset_index + 4] = loop_offset_bytes
	print("VGM adjusted loop offset: {:X}".format(adjusted_loop_offset))

	# Make immutable bytes object since this will be handled by another thread
	processed_vgm.data = bytes(vgm_bytes)
	print(processed_vgm)

	if flag_writes_removed > 0:
		print("Removed redundant flag writes: {:X}".format(flag_writes_removed))

	return processed_vgm

###

dev = usb.core.find(idVendor=0x1d50, idProduct=0x6147)

if dev is None:
	print('Bitsy device found not found')
	sys.exit(1)

# Initial USB config

dev.set_configuration()

data_ep = get_data_ep(dev)
status_ep = get_status_ep(dev)

# Read a VGM to send

if len(sys.argv) != 2:
	print('Expected one argument with filename')
	sys.exit(1)

filename = sys.argv[1]

vgm = read_vgm(filename)
processed_vgm = preprocess_vgm(vgm)
send_pcm_blocks(dev, data_ep, processed_vgm.pcm_blocks)
send_vgm(dev, data_ep, processed_vgm.data)

(status_thread, status_stopping_event) = start_polling_status(dev, status_ep, data_ep, processed_vgm)

while True:
	try:
		time.sleep(0.5)
	except KeyboardInterrupt:
		status_stopping_event.set()
		status_thread.join()
		sys.exit(1)

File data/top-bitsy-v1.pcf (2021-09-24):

# YM2610 PCM Mux (discrete logic)

set_io ym_io[0] 20
set_io ym_io[1] 13
set_io ym_io[2] 21
set_io ym_io[3] 12

set_io mux_sel[0] 23
set_io mux_sel[1] 27
set_io mux_sel[2] 26

set_io mux_oe_n 25
set_io pcm_load 4
set_io rmpx 10
set_io pmpx 11

# YM3016

set_io dac_clk 3
set_io dac_sh1 34
set_io dac_sh2 32
set_io dac_so 9

# SPDIF

set_io spdif_out 45

# MIDI

set_io midi_rx 48

# SPI
set_io spi_io[0] 14
set_io spi_io[1] 17
set_io spi_io[2] 18
set_io spi_io[3] 19

set_io -nowarn spi_clk 15
set_io -nowarn spi_flash_cs_n 16
set_io -nowarn spi_ram_cs_n 6

# USB
set_io -nowarn usb_dp 42
set_io -nowarn usb_dn 38
set_io -nowarn usb_pu 37

# UART
set_io -nowarn uart_rx 47
set_io -nowarn uart_tx 44

# Clock
set_io -nowarn clk_in 35

# Button (bitsy)
set_io -nowarn btn 2

# Button (PCB)
set_io -pullup yes -pullup_resistor 3P3K btn_a 28
set_io -pullup yes -pullup_resistor 3P3K btn_b 31
 
# Leds
set_io -nowarn rgb[0] 39
set_io -nowarn rgb[1] 40
set_io -nowarn rgb[2] 41

# Both an IO + LED on 24?
#set_io led 25

# YM2610

set_io ym_clk 46
set_io ym_shift_load 43
set_io ym_shift_out 36

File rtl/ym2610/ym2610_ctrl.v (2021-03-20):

// ym2610_ctrl.v
//
// Copyright (C) 2021 Dan Rodrigues <danrr.gh.oss@gmail.com>
//
// SPDX-License-Identifier: CERN-OHL-S-2.0

`default_nettype none

module ym2610_ctrl(
	input clk,
	input reset,

	// 8MHz clk enable events

	input ym_clk_rose,
	input ym_clk_fell,

	// Wishbone interface

	input [2:0] wb_addr,
	input [7:0] wb_wdata,
	input wb_we,
	input wb_cyc,

	output reg [31:0] wb_rdata,
	output reg wb_ack,

	// Shift control

	output ctrl_shift_out,
	output ctrl_shift_load
);
	// --- Wishbone ---

	// Address map:

	// 00-03: YM2610 port A/B writing (address/data)
	// 04-07: YM2610 reset control

	always @(posedge clk) begin
		wb_ack <= wb_cyc && !fifo_full && !wb_ack;
		wb_rdata <= (wb_cyc && !wb_we) ? {31'b0, fifo_full} : 32'b0;
	end

	// --- Write-command FIFO ---

	// Writes shouldn't block the CPU because:
	// - The YM2610 itself has a very long delay between writes (83 cycles @ 8MHz)
	// - The shifters here take a while to work
	//
	// Optimizing the shifter implementation isn't useful because the 2610 the bottleneck

	// FIXME: 12bits where an extra bit flags that this is a reset
	wire [10:0] fifo_wdata = {wb_addr[2:0], wb_wdata[7:0]};
	wire fifo_we = wb_cyc && wb_we && !wb_ack && !fifo_full;
	wire fifo_full;

	wire [7:0] fifo_ym_data;
	wire [1:0] fifo_ym_address;
	wire fifo_ym_reset;

	wire fifo_read_en = !busy && !fifo_empty;
	wire fifo_empty;

	fifo_sync_ram #(
		.DEPTH(512),
		.WIDTH(11)
	) ym_ctrl_fifo (
		.clk(clk),
		.rst(reset),

		.wr_data(fifo_wdata),
		.wr_ena(fifo_we),
		.wr_full(fifo_full),

		.rd_data({fifo_ym_reset, fifo_ym_address, fifo_ym_data}),
		.rd_ena(fifo_read_en),
		.rd_empty(fifo_empty)
	);

	wire ym_ctrl_write_en = fifo_read_en && !fifo_ym_reset;
	wire ym_reset_en = fifo_read_en && fifo_ym_reset;

	// --- YM2610 control ---

	// Write handling:

	// 17 after addr
	// 83 after data write
	localparam WRITE_DELAY = 83;

	reg [$clog2(WRITE_DELAY):0] write_delay_counter;
	wire ym_data_busy = (write_delay_counter > 0);

	always @(posedge clk) begin
		if (reset) begin
			write_delay_counter <= 0;
		end else begin
			if (ym_data_written) begin
				write_delay_counter <= WRITE_DELAY;
			end else if (ym_data_busy && ym_clk_rose) begin
				write_delay_counter <= write_delay_counter - 1;
			end
		end
	end

	// Shift register write FSM:

	localparam [2:0]
		STATE_ADDRESS_SETUP = 0,
		STATE_REG_WRITE = 1,
		STATE_REG_WRITE_HOLD = 2,
		STATE_WRITING = 3,
		STATE_IDLE = 4;

	wire busy = (state != STATE_IDLE);

	reg [2:0] state;
	reg [2:0] next_state;

	reg ym_data_written;
	reg shift_needs_load;

	reg [7:0] din_write;
	reg [1:0] address_write;

	reg [7:0] reg_address_pending_write [0:1];
	reg [7:0] reg_data_pending_write;

	reg [1:0] address_shift;
	reg [7:0] din_shift;
	reg cs_n_shift;
	reg wr_n_shift;
	reg ic_n_shift;

	always @(posedge clk) begin
		if (reset) begin
			ic_n_shift <= 0;
			cs_n_shift <= 1;
			wr_n_shift <= 1;

			address_write <= 0;
			din_write <= 0;

			ym_data_written <= 0;

			shift_needs_load <= 1;
			state <= STATE_WRITING;
			next_state <= STATE_IDLE;
		end else begin
			shift_needs_load <= 0;
			ym_data_written <= 0;

			case (state)
				STATE_IDLE: begin
					if (ym_ctrl_write_en) begin
						if (fifo_ym_address[0]) begin
							address_write <= {fifo_ym_address[1], 1'b0};
							din_write <= reg_address_pending_write[fifo_ym_address[1]];
							reg_data_pending_write <= fifo_ym_data;

							state <= STATE_ADDRESS_SETUP;
						end else begin
							reg_address_pending_write[fifo_ym_address[1]] <= fifo_ym_data;
						end
					end else if (ym_reset_en) begin
						// Unconditionally clear reset, could add support to reset again if needed
						ic_n_shift <= 1;
						cs_n_shift <= 1;
						wr_n_shift <= 1;

						shift_needs_load <= 1;
						state <= STATE_WRITING;
						next_state <= STATE_IDLE;
					end
				end
				STATE_ADDRESS_SETUP: begin
					address_shift <= address_write;
					cs_n_shift <= 1;
					wr_n_shift <= 1;
					din_shift <= din_write;

					shift_needs_load <= 1;
					state <= STATE_WRITING;
					next_state <= STATE_REG_WRITE;
				end
				STATE_REG_WRITE: begin
					address_shift <= address_write;
					cs_n_shift <= 0;
					wr_n_shift <= 0;
					din_shift <= din_write;

					// Can't start the write until write-delay is satisfied
					if (!ym_data_busy) begin
						shift_needs_load <= 1;
						state <= STATE_WRITING;
						next_state <= STATE_REG_WRITE_HOLD;
					end
				end
				STATE_REG_WRITE_HOLD: begin
					// Needed to start the write-delay-counter *only* for data writes
					// Address writes are quick enough that no delay is needed
					if (address_write[0]) begin
						ym_data_written <= 1;
					end

					address_shift <= address_write;
					cs_n_shift <= 1;
					wr_n_shift <= 1;
					din_shift <= din_write;

					if (!address_write[0]) begin
						// Reg address will be written, write data next
						address_write[0] <= 1;
						din_write <= reg_data_pending_write;

						next_state <= STATE_ADDRESS_SETUP;
					end else begin
						// Reg address and data will be both written
						next_state <= STATE_IDLE;
					end

					shift_needs_load <= 1;
					state <= STATE_WRITING;
				end
				STATE_WRITING: begin
					if (shift_completed) begin
						state <= next_state;
					end
				end
			endcase
		end
	end

	// Output shift register:

	// External shift reg is clocked on posedge
	// Output here is shifted on negedge

	localparam SHIFT_BITS = 13;
	localparam SHIFT_MSB = SHIFT_BITS - 1;

	reg [SHIFT_MSB:0] shift;
	assign ctrl_shift_out = shift[SHIFT_MSB];

	reg [2:0] shift_load_r;
	assign ctrl_shift_load = shift_load_r[2];

	reg [3:0] shift_count;
	reg shift_completed;
	reg shifting;

	reg awaiting_ym_clk_fall;

	wire [SHIFT_MSB:0] shift_preload = {
		ic_n_shift, cs_n_shift, wr_n_shift, address_shift, din_shift
	};

	always @(posedge clk) begin
		if (reset) begin
			shift_completed <= 0;
			shift_load_r <= 0;
			shifting <= 0;

			awaiting_ym_clk_fall <= 0;
		end else begin
			shift_completed <= 0;
			shift_load_r <= shift_load_r << 1;

			if (shift_needs_load) begin
				shift <= shift_preload;
				shift_count <= 0;
				shifting <= 1;
				awaiting_ym_clk_fall <= 1;
			end else if (shifting && awaiting_ym_clk_fall) begin
				if (ym_clk_fell) begin
					awaiting_ym_clk_fall <= 0;
				end
			end else if (shifting && ym_clk_rose) begin
				shift <= shift << 1;

				if (shift_count == SHIFT_MSB) begin
					shift_load_r <= 3'b111;

					shift_completed <= 1;
					shifting <= 0;
				end

				shift_count <= shift_count + 1;
			end
		end
	end

endmodule

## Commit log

2021-03-07 Restore repo
    [ym2610-pcb.kicad_pcb, ym2610-pcb.sch]
2021-03-07 doc: add partially assembled, but working, PCB photo
2021-03-08 hw/sw: add YM2610 command FIFO and hardware timer for delays
2021-03-08 pcb: bump version from v1.0.0 to tentative v1.0.1a
    [ym2610-pcb.kicad_pcb]
2021-03-10 hw/sw: extend reset pulse (min 192 cycles @ 8MHz)
    [ym2610_ctrl.v]
2021-03-10 pcb: replace LV1T34 with LVC1G34 as S/PDIF coax buffer
    The earlier design used the LVC part but to remove a unique item from BOM, it was replaced with another LV1 part. This was a mistake as the LV1T34 can't quite drive the coax load (vs. 24mA on the LVC1G34).
    [ym2610-pcb.kicad_pcb, ym2610-pcb.sch]
2021-03-11 rtl/sw/util: various bits of cleanup and groundwork for command streaming
2021-03-15 sw/rtl: add 2 extra PCB buttons and FM/PCM control
2021-03-17 sw: add build-time filtering for FM
2021-03-19 rtl: eliminate a few unnecessary resets
    [adpcm_b_reader.v]
2021-03-20 rtl / sw: fix ADPCM-B playback glitch
    [adpcm_a_reader.v, adpcm_b_reader.v]
2021-03-20 sw / rtl: revised timer setup for accuracy
    New approach uses a timer that always keeps decrementing rather than suspending when timer expires
2021-03-20 sw: allow timer to be reset to zero now
2021-03-21 doc: update README and photo or partial assembly
2021-03-21 pcb: misc. cleanup in analog section
    * added net-tie and dedicated return for headphone to avoid running over much of the DAC circuit
    * route SSG on back layer
    * ground fill on top
    [ym2610-pcb.kicad_pcb, ym2610-pcb.sch]
2021-03-21 sch: added rev. text
    [ym2610-pcb.sch]
2021-03-21 pcb / sch: added CERL-OHL license
    [ym2610-pcb.kicad_pcb, ym2610-pcb.sch]
2021-03-28 pcb: tentative v1.0.1
    [ym2610-pcb.kicad_pcb, ym2610-pcb.sch]
2021-03-28 util: minor script corrections
    [vgm_preprocess.py]
2021-03-29 util: fix PCM block sorting for non-unified games
    ADPCM-A/B use separate address spaces in older tracks and this needs to be respected when PCM blocks are remapped
    [vgm_preprocess.py]
2021-04-01 util: fix various issues with VGM converter script
    [usb_ctrl.py, vgm_convert.py, vgm_preprocess.py]
2021-04-01 util: removed PCM block merging which isn't needed anymore
    It also caused issues of its own
    [vgm_preprocess.py]
2021-04-05 rtl: added ENABLE_MIDI parameter
    This should be 0 if the MIDI input components are populated or else the UART will have a floating input, possibly affecting software.
2021-04-07 doc: updated PCB photo and README
2021-08-29 sw: add sequence counter to filter unexpected requests
2021-09-09 rtl: fix ADPCM-B reader glitches that affected a few chips
    [spi_mem.v]
2021-09-24 pcb: v1.1.0
    * Layout cleanup and removal of now-redundant parts
    * Fixed lots of plane breakage near center of board
    * Added 47pF caps to RMPX/PMPX
    * Updated .pcf with reassigned pins
    [ym2610-pcb.kicad_pcb, ym2610-pcb.sch]
2021-09-26 sch: minor cleanup
    [ym2610-pcb.sch]
2021-09-26 doc: add assembled PCB of v1.1.0
